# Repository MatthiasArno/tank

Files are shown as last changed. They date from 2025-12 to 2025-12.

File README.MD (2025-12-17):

# Ultrasonic Level Meter with Temperature Sensors, Dashboard and Chatbot Integration

<table>
  <tr>    
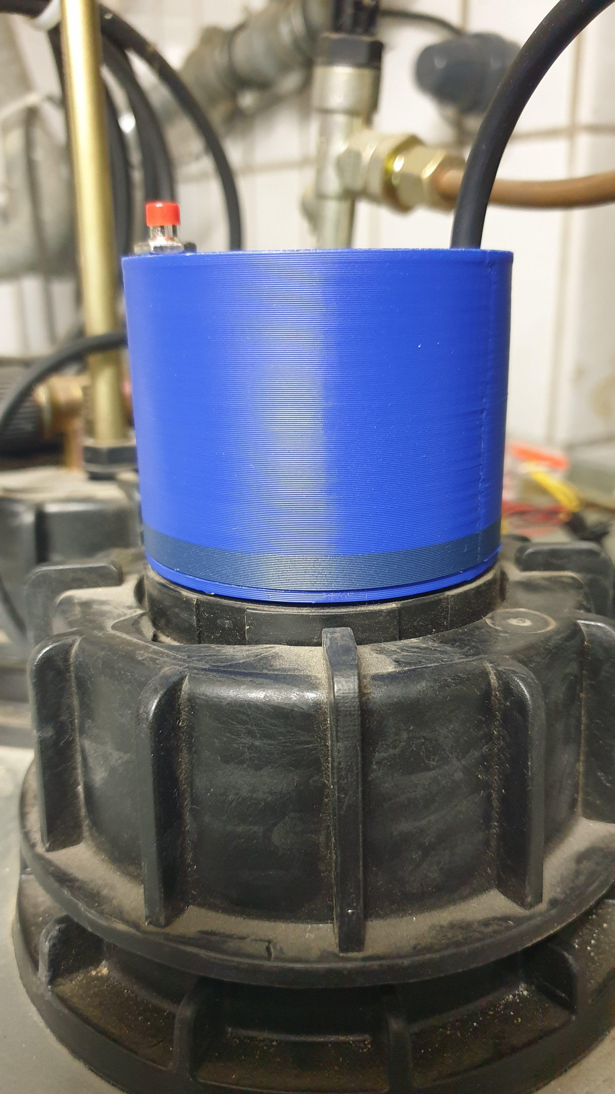
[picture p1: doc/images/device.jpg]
    <td width="50%"></td>
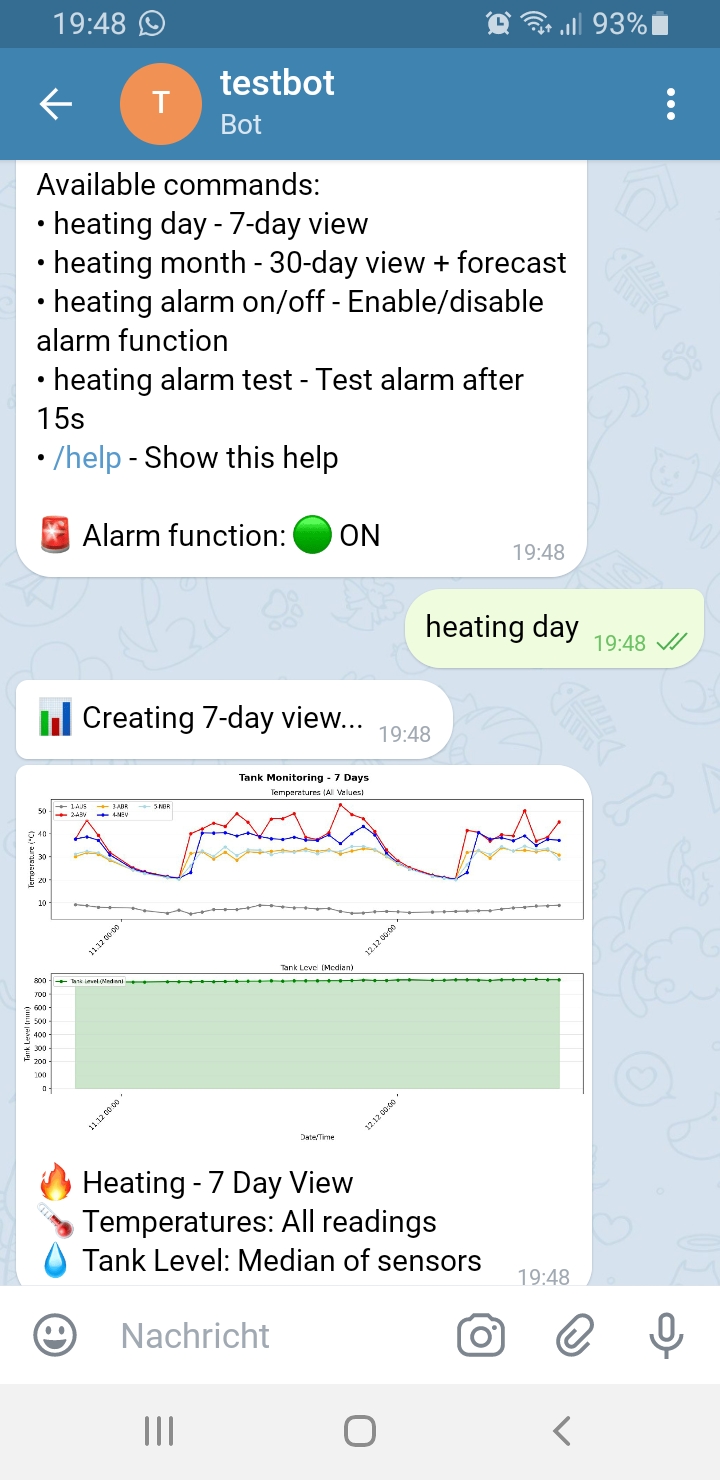
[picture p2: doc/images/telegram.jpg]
    <td width="50%"></td>
  </tr>
</table>
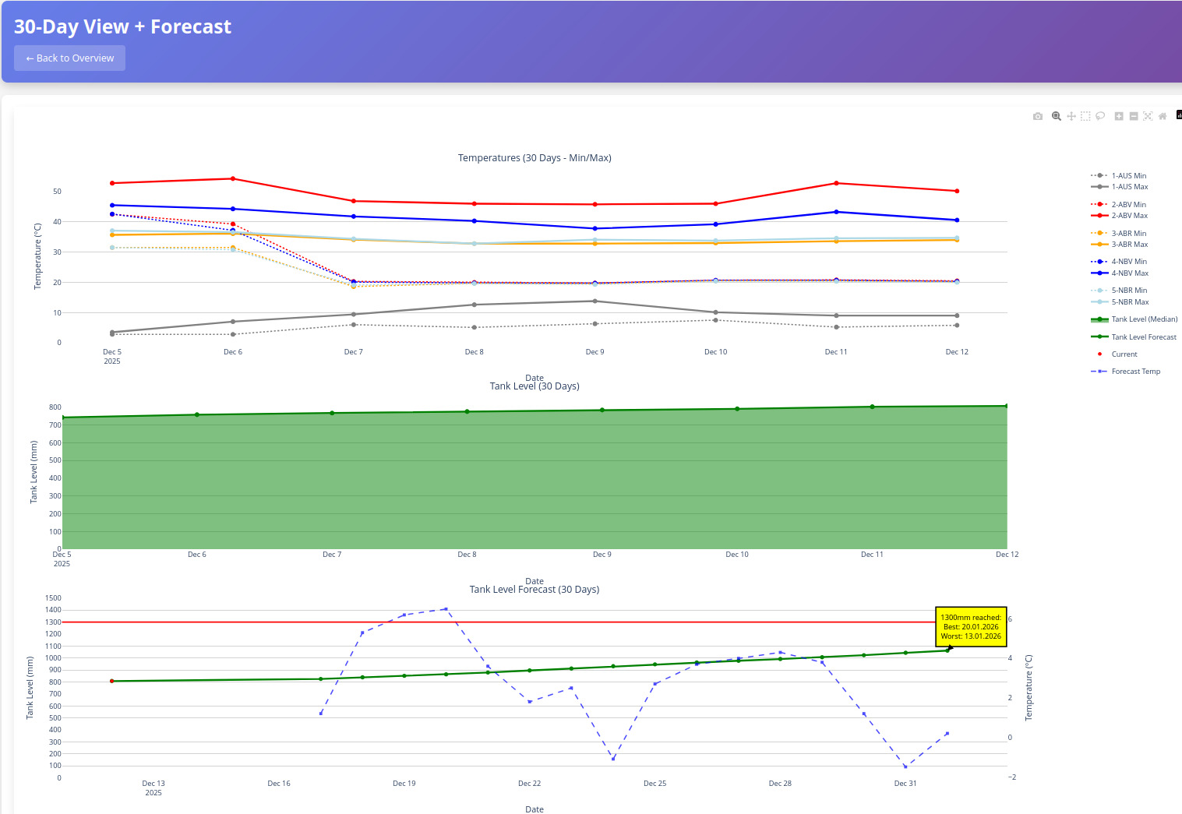
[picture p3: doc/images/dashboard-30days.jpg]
</td>
 
# Overwiew

This tank level monitor measures the current fill level and temperatures using ultrasonic SR04 and DS18B20 sensors.
With this data, I want to learn more about the future sizing of a heat pump—see also my initial thoughts on this [here](https://github.com/MatthiasArno/heizungsgesetz). The features in detail:

* Mechanical
  * 3dp parts available
  * 3xAA battery powered
* ESP32-based ultrasonic level meter with support for 5 external temperature sensors
  * Web interface for sensor readings, log download and software update
  * MQTT publishing of sensor data
* Raspberry Pi server
  * Statistics dashboard
  * Telegram bot (for remote access and alarms)
  * Alerting when temperatures fall below critical values
  * Tank level forecasting using historical data and weather forecasts

## Security & Disclaimer

**IMPORTANT:** This is a hobby project for personal, non-commercial use in controlled environments. It is provided "as-is" without warranty. By using this project, you accept all risks and responsibilities.

**Known Security Limitations:**

* WiFi credentials stored in plaintext on ESP32/.env
* Web interface is http and has no authentication
* MQTT communication unencrypted by default
* No secure boot implementation

**Required Security Measures:**

* **MANDATORY:** Isolate device on guest network with no internet access
* **MANDATORY:** Secure physical access to prevent credential theft
* **MANDATORY:** Set your Telegram user-id to prevent unauthorized bot access
* **MANDATORY:** Never port-forward the web interface to the internet (applies to device and dashboard server)
* Use dedicated MQTT server (e.g., Raspberry Pi)
* Run services as non-root user (default: **tank**)

**Recommended Hardening (currently not implemented):**

* Enable ESP32 secure boot
* Implement MQTT client authorization
* Add web interface authentication

**You are solely responsible for:**
* Network security and isolation
* Physical device security
* Any consequences of unauthorized access
* Compliance with local regulations

**This device is NOT suitable for critical infrastructure or commercial deployments.**

## Safety

**WARNING:** This device operates near flammable liquids. Improper use may result in fire, injury, or property damage.

**FIRE HAZARD - Critical Requirements:**

* **ONLY use standard alkaline AA batteries** - Never use rechargeable batteries
* Rechargeable batteries can supply high currents causing excessive heat and fire risk
* Installation on oil tanks or near flammable materials requires extreme caution
* Regularly inspect for signs of battery leakage, corrosion, or overheating

**Battery Specifications:**

* Type: Standard alkaline AA batteries only
* Expected lifetime: ~1 year under normal conditions (varies with environmental conditions, see below)
* Replace immediately if device behavior becomes erratic

**Installation Safety:**

* Mount securely to prevent falls into tank or flammable materials
* Ensure all connections are properly insulated and separated

**User Responsibility:**

You assume all liability for safe installation, operation, and maintenance. The author accepts no responsibility for fire, equipment damage, or personal injury resulting from use of this device.

**If unsure about safe installation, consult a qualified professional.**

## Operation

* Sensors
  * 1-AUS : Outside Temperature (Außentemperatur)
  * 2-ABV: Old Building Flow (Altbau Vorlauf)
  * 3-ABR: Old Building Return (Altbau Rücklauf)
  * 4-NBV: New Building Flow (Neubau Vorlauf)
  * 5-NBR: New Building Return (Neubau Rücklauf)
  * device: ESP32, +20 above room temp right after power up (when sending mqtt messages)
* The device sends an MQTT message each full hour with topics
  * tank/1/level, with level=a,b,c,1, beeing 3 consecutive level measurements in mm plus 1 (a constant, see code)
  * tank/sensorID/temp, with sensorID=device or serial ID of the temperature sensor or its name-mapping
* Dynamic sleep time and report
  * Dynamic sleep less than one hour under following conditions
    * 15 mins if 1-AUS falls below 3 degrees Celsius
    * 5 mins if 1-AUS below -8 degrees Celsius
  * Report sent (alarm)
    * If any heating temperature falls below 17 degree
    * If 1-AUS is below 4 degree Celsius and any heating temperature falls below 25 degree
* Pushing the KEY button for 2..3s will restart in WebMode
  * Terminate by the WebIF Exit Button
  * Terminate by pushing the button for longer than 10s
  * Terminate by closing the browser window (60 seconds without request, e.g. time update in the WebIF)  
* Blue LED
  * Lights directly after restart until deep_sleep
  * Flashes 100ms with 1s period in WebMode
* Power LED
  * Is desoldered to save energy

## Programming

https://micropython.org/download/ESP32_GENERIC/

```bash
# Setup micropython V1.26.1 (recent as of this days)
esptool erase_flash
esptool --baud 460800 write_flash 0x1000 ESP32_BOARD_NAME-DATE-VERSION.bin
# Compile the biggest files
mpy-cross main_tank.py microdot.py
# Keep KEY button pressed on device if there is already a SW installed, then copy the files
# Never write programms that immediately shutdown/sleep the device: this needs a reflashing of the micropython image
mpremote cp main_tank.mpy microdot.mpy pf_esp32.py main.py env.py :/
# Keep button pressed, then CTRL-C/CTRL-D to restart in WEB Mode
```

# Micropython

It is required to compile main_tank.py, microdot.py, otherwise out of memory or strange behavior will be the result. 

Cross compile: https://docs.micropython.org/en/v1.14/develop/gettingstarted.html
mpy-cross ...

## Dependencies

* mpremote mip install umqtt.simple

## ESP32 D1 WROOM Resources
[ESP32 D1 Pinout](https://www.az-delivery.de/en/blogs/azdelivery-blog-fur-arduino-und-raspberry-pi/das-dreiundzwanzigste-turchen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)

## Modifications

* Remove Power Led (red) to save energy

## Pin Usage

USB points to south, only pins on the east upper and lower side are used. Color of the cable depends what you have available.

Outer row, from north, 4x:
- GND (black)
- GPIO27: SR04_ECHO_PIN (green)
- GPIO25: SR04_TRIGGER_PIN (yellow)
- GPIO32: SR04_PWR_OUT (POWER) (red)

Inner row, from south, 6x:
- GPIO17: Sensor_PLUS (white)
- GPIO16: Sensor_BUS (grey)
- GND: Batt_GND, Sensor_GND, KEY_GND
- 5V: Batt_PLUS
- GPIO15: KEY_IN (internal Pullup, RTC capable wakeup)
- nc

Sensor Cable:
- Brown : GND
- Grey: Signal Temp
- Yello : +3.3V Temp
- White : nc
- Green :nc

## Sensor Codings

Up to 5 external temperature sensors will be supported. 1wire sensors have a unique device id, which will be reported along with its temperature value. For better reading, the last 2 hex digits of this id are mapped onto a clear name, e.g. 1-AUS. See code for the mapping.

Example: 28d35452000000d6 : -> translates to { "d6": "1-AUS"... }

## WiFi Connection

Unstable WiFi results in strange behavior of the device. When using a repeater, do not operate it in mesh mode since esp32 always tries to connect to the mesh master, regardless of the signal strength of your repeater. Instead, give the repeater a dedicated SSID and connect to it.

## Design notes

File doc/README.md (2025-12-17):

# Tank Monitoring System

Server applications for visualization, messaging and analysis of heating data.

## Structure

```
rpi/
├── db/                     # Database directory
│   └── tank_data.db       # SQLite database (created automatically)
└── src/                    # Source Code
    ├── api/                    # FastAPI Dashboard
    │   ├── dashboard.py       # Main application with Plotly
    │   └── templates/         # HTML Templates
    │       ├── index.html     # Home page
    │       └── view.html      # Chart view
    ├── database/              # Database modules
    │   └── db_handler.py     # Database handler
    ├── mqtt/                  # MQTT Client
    │   └── subscriber.py     # MQTT Subscriber
    ├── utils/                 # Utility functions
    ├── config.py             # Configuration
    ├── run_subscriber.py     # Starts MQTT Subscriber
    ├── run_dashboard.py      # Starts Dashboard
    ├── export_db.py          # DB Export Tool (R-FUN-700)
    ├── statistic_db.py       # Statistics Analysis Tool (F-STAT-800)
    ├── debug_db.py           # Database debug tool
    └── requirements.txt      # Python Dependencies
```

## Installation

### 1. Create Virtual Environment (recommended)

```bash
cd rpi/src
python3 -m venv .venv
source .venv/bin/activate
```

### 2. Install Python Dependencies

```bash
# In the activated venv:
pip install -r requirements.txt
```

**Important**: If you use a venv, you must activate it before each manual start:
```bash
source .venv/bin/activate
```

For systemd services, the absolute path to venv Python is used (see below).

### 3. Create Configuration

```bash
# Copy env.example to .env
cp env.example .env

# Edit .env and add your values
nano .env
```
### 4. Install Mosquitto MQTT Broker (if not already installed)

```bash
sudo apt update
sudo apt install mosquitto mosquitto-clients
sudo systemctl enable mosquitto
sudo systemctl start mosquitto
```
# Database (optional, default: ../db/tank_data.db)
# DATABASE_PATH=/custom/path/to/tank_data.db

### Start MQTT Subscriber

The subscriber receives MQTT messages and writes them to the database:

```bash
python3 run_subscriber.py
```

### Start Dashboard

The dashboard displays the data graphically:

```bash
python3 run_dashboard.py
```

Open dashboard: http://localhost:8000

### Start Messenger

```bash
python3 run_telegram_bot.py
```

Using a loud alarm tone:
* Download a loud sound, e.g. copy alarm.mp3 to /Notifications/alarm.mp3
* Telegram: Settings/Notifications
  * Private Chats: Sound+Vibration. A default must be enabled
  * Settings for system notifications (at the bottom): All customized channels at a glance
  * Customize channel directly: click on the icon in the channel, Notifications/Customize, then select your own alarm tone
* Phone:
  * Settings/Device maintenance/Battery/App power management/Apps that won't be put to sleep => Add Telegram
  * Settings/Apps/Telegram/Mobile data connection => Allow background data

### DB Export Tool

Exports database contents with optional date filters:

```bash
# Export all data
python3 export_db.py

# From start date
python3 export_db.py 2025-12-01

# Date range
python3 export_db.py 2025-12-01 2025-12-31
```

### Statistics Tool

Analyzes heating oil consumption depending on outside temperature:

```bash
# Analyze all data
python3 statistic_db.py

# From start date
python3 statistic_db.py 2025-12-01

# Date range
python3 statistic_db.py 2025-12-01 2025-12-31
```

The tool:
- Calculates daily consumption (dH/dT) normalized to outside temperature
- Performs linear regression and evaluates suitability
- Creates graphs PNG with actual data and regression line
- Saves graphs in the `output/` directory

### Debug Tool

Shows database statistics and diagnoses problems:

```bash
python3 debug_db.py
```

## Features

### MQTT Topics

The subscriber subscribes to the following topics:
- `tank/1/level` - Level measurements (3 values + ignored value)
- `tank/1/temp/1-AUS` - Outside temperature
- `tank/1/temp/2-ABV` - Old building supply (R-FUN-110)
- `tank/1/temp/3-ABR` - Old building return (R-FUN-110)
- `tank/1/temp/4-NBV` - New building supply (R-FUN-110)
- `tank/1/temp/5-NBR` - New building return (R-FUN-110)
- `tank/1/temp/device` - Ignored

### Dashboard

FastAPI-based dashboard with two main views:

### R-FUN-510/520/530: 30-Day View

- Shows min/max values of all temperature sensors over 30 days
- Dotted lines for min values, solid lines for max values
- Color coding (R-FUN-530):
  - ABV (Old building supply): Red
  - ABR (Old building return): Orange
  - NBV (New building supply): Blue
  - NBR (New building return): Light blue
  - Level: Green
- Level: Last value of the day (median of 3 sensors)

### 7-Day View

- Shows all values (hourly aggregated) over 7 days
- Solid lines for all sensors
- Level: Median of 3 sensors
- Same color coding as 30-day view

### DB Export Tool

Command-line tool for exporting database data:

```bash
python3 export_db.py [STARTDATE] [ENDDATE]
```

- No parameters: All data
- One parameter: From start date
- Two parameters: Date range
- Date format: YYYY-MM-DD

### Statistical Analysis

Analyzes the relationship between heating oil consumption and outside temperature:

```bash
python3 statistic_db.py [STARTDATE] [ENDDATE]
```

Functions:
- Calculates daily consumption rate normalized to temperature difference to 20°C: `dH/dT = (H_end - H_start) / (T_mean - 20)` [mm/Kelvin]
- Optional date filters (analogous to export_db.py)
- Linear regression with statistical evaluation (R², p-value)
- Graphical representation:
  - X-axis: Outside temperature [°C]
  - Y-axis: Daily consumption [mm]
  - Shows measurement data as points and regression line
  - Saves as PNG and PDF in `output/` directory

## Important Note: Dashboard Display

The dashboard shows data from the last 7/30 days by default. If no data is available in this time period (e.g., with older test data), the logic has been improved:

- **Automatic fallback display**: If no current data is available, the last available data is automatically displayed
- **Debug tool**: With `python3 debug_db.py` you can check what data is in the DB and how old it is

## Database

The SQLite database is stored by default in `rpi/db/tank_data.db` and contains two tables:

- `level_measurements`: Level measurements
- `temp_measurements`: Temperature measurements

Both tables contain timestamp, tank ID, and the respective measurement values.

**Database location**:
- Default: `rpi/db/tank_data.db`
- Automatically created on first start
- Can be changed via `DATABASE_PATH` environment variable

## Debian Package Installation

A Debian package is available for easy installation on the Raspberry Pi. See the *build-deb-fpm.sh* for systemd configuration and what gets packed.

### Create Package (on development computer)

Prerequisites:
```bash
sudo apt-get install -y ruby ruby-dev rubygems build-essential
sudo gem install --no-document fpm
```

Build package:
```bash
cd /path/to/project
./build-deb-fpm.sh
```

Creates: `tank-monitoring_0.1.0_armhf.deb`

### Install Package on RPI

```bash

# Install Mosquitto
sudo apt-get install mosquitto
# Create file
# etc/mosquitto/conf.d/rpiserver.conf
# listener 1883 0.0.0.0
# allow_anonymous true
sudo systemctl enable mosquitto
sudo systemctl start mosquitto

# Copy package to RPI
scp tank-monitoring_0.1.0_armhf.deb myuser@myrpi:~

# Install on RPI
ssh myuser@myrpi
sudo dpkg -i tank-monitoring_0.1.0_armhf.deb
sudo apt-get install -f  # If dependencies are missing
```

### Configuration After Installation

```bash
# 1. Create bot configuration
sudo cp /etc/tank/bot.conf.example /etc/tank/bot.conf
sudo nano /etc/tank/bot.conf
```

Add:
```bash
TELEGRAM_BOT_TOKEN=your-bot-token-here
TELEGRAM_MY_ID=your-telegram-user-id
```

```bash
# 2. Enable and start services
sudo systemctl enable tank-subscriber tank-telegram
sudo systemctl start tank-subscriber tank-telegram

# Optional: Enable dashboard
sudo systemctl enable tank-dashboard
sudo systemctl start tank-dashboard
```

### Service Management with tank-ctl

The package installs a helper script for easy service management:

```bash
# Start services
tank-ctl start

# Stop services
tank-ctl stop

# Restart services
tank-ctl restart

# Show status of all services
tank-ctl status

# View logs
tank-ctl logs mqtt        # MQTT Subscriber logs
tank-ctl logs bot         # Telegram Bot logs
tank-ctl logs dashboard   # Dashboard logs

# Enable/disable autostart
tank-ctl enable
tank-ctl disable
```

### Control Individual Services

```bash
# MQTT Subscriber only
sudo systemctl start tank-subscriber
sudo systemctl stop tank-subscriber
sudo systemctl status tank-subscriber

# Telegram Bot only
sudo systemctl start tank-telegram
sudo systemctl stop tank-telegram
sudo systemctl status tank-telegram

# Dashboard only
sudo systemctl start tank-dashboard
sudo systemctl stop tank-dashboard
sudo systemctl status tank-dashboard
```

### Installation Paths

The Debian package installs to:
- Application: `/opt/tank/rpi/`
- Python venv: `/opt/tank/rpi/.venv/`
- Database: `/opt/tank/rpi/db/tank_data.db`
- Configuration: `.env' : provide your personal configuration file
- Systemd services: `/etc/systemd/system/tank-*.service`
- Helper script: `/usr/bin/tank-ctl`

### Uninstallation

```bash
# Services are automatically stopped and disabled
sudo dpkg -r tank-monitoring

# Complete removal including database and configuration
sudo dpkg --purge tank-monitoring
sudo rm -rf /opt/tank
```

### Logs After Installation

```bash
# Real-time logs
sudo journalctl -u tank-subscriber -f
sudo journalctl -u tank-telegram -f
sudo journalctl -u tank-dashboard -f

# Or with tank-ctl
tank-ctl logs mqtt
tank-ctl logs bot
tank-ctl logs dashboard
```

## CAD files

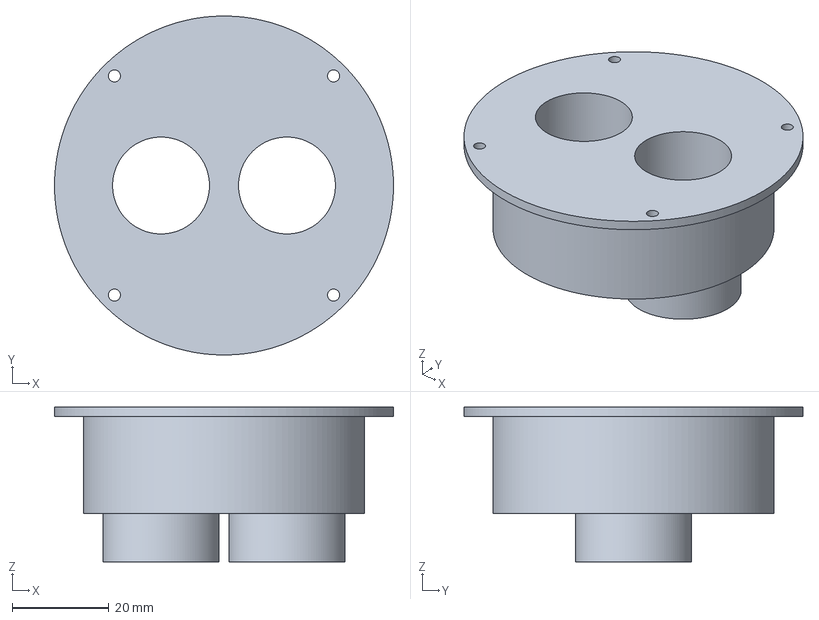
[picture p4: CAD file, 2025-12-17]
mech/bambu/tank-BBoden.amf
70.0 x 70.0 x 32.0 mm

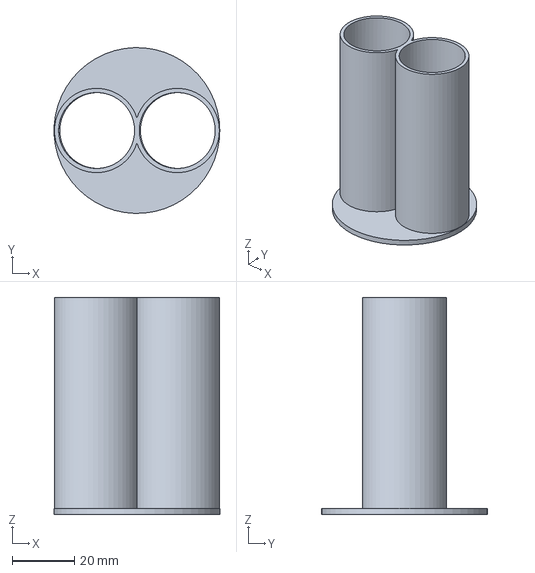
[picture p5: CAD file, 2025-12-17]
mech/tank.FCStd
53.4 x 53.5 x 70.0 mm

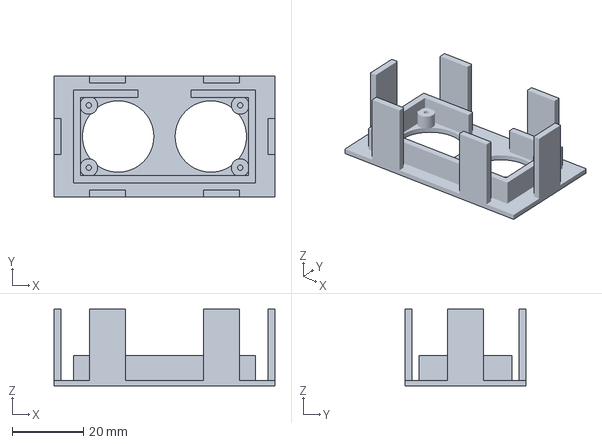
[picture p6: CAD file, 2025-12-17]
mech/bambu/tank-BHalter.amf
62.0 x 34.0 x 21.5 mm

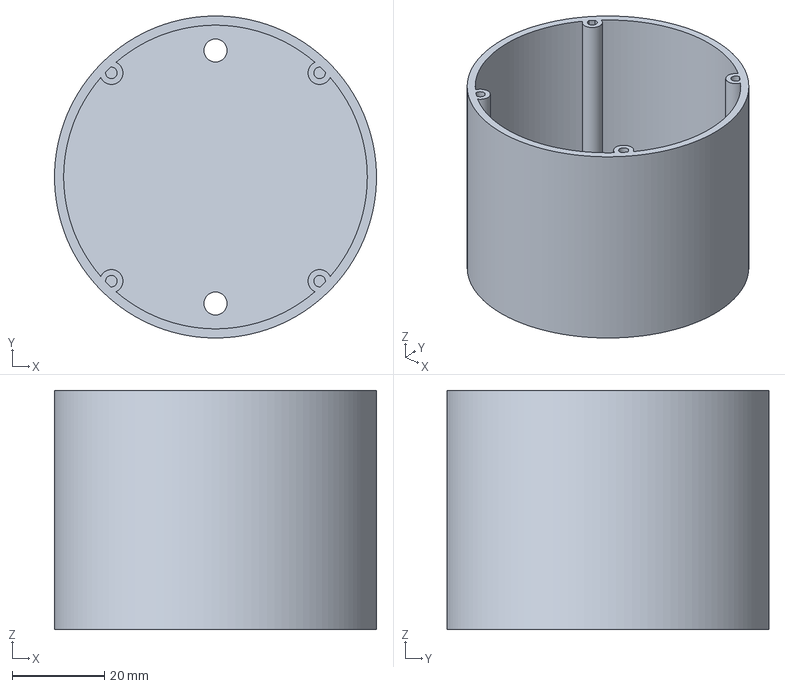
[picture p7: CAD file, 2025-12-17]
mech/bambu/tank-BDeckel.amf
70.0 x 70.0 x 52.0 mm

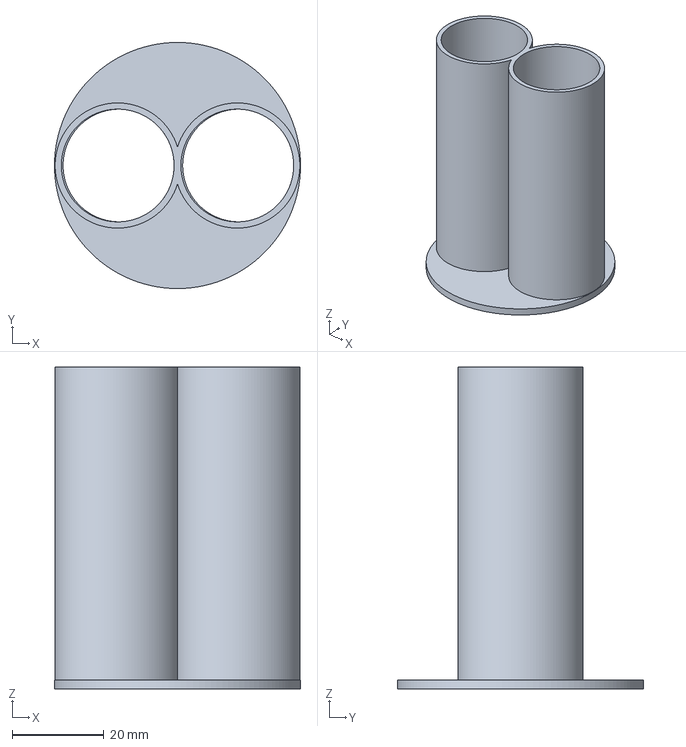
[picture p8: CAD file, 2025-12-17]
mech/bambu/tank-BSoundPipe.amf
53.5 x 53.5 x 70.0 mm

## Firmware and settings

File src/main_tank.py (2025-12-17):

"""
Tank Level Measurement System
Measures oil tank level via HC-SR04 ultrasonic sensor
Supports ESP32 and Raspberry Pi Pico
"""

import time
import network
import ntptime
import machine
import gc
import os
import sys
from machine import Pin, WDT

# Use ujson for MicroPython (more efficient than standard json)
try:
    import ujson as json
except ImportError:
    import json

try:
    import uasyncio as asyncio
except ImportError:
    import asyncio

try:
    import umqtt.simple as mqtt
except ImportError:
    mqtt = None

try:
    from microdot import Microdot, Response, Request
except ImportError:
    print("ERROR: Microdot not found!")
    raise

from env import *

try:
    from ds18x20 import DS18X20
    from onewire import OneWire
except ImportError:
    DS18X20 = None
    OneWire = None


try:
    from esp32 import wake_on_ext0
except ImportError:
    wake_on_ext0 = None

# Detect platform
try:
    from pf_esp32 import *
    PLATFORM = "ESP32"
except ImportError:
    try:
        from pf_rpi import *
        PLATFORM = "RPI_PICO"        
    except ImportError:
        print("ERROR: No platform file!")
        raise


#MQTT_SERVER = "your-server" (use env.py instead!)
ntptime.host = "192.53.103.104"
Request.max_content_length = 256 * 1024
Request.max_body_length = 2 * 1024

# Global state for restart
launch_restart_pending = False


# Temperature sensors, sorted by name when returned
temp_id_to_name={ "device": "device", "d6" : "1-AUS", "5a" : "2-ABV", "2b" : "3-ABR", "89" : "4-NBV", "49": "5-NBR"}


# Wakeup each minutes, relative to the last full hour
TIMEOUT_REPORT_WAKEUP=60*60
# T_aus determines the wakeup time
T_aus=0
# Temperatures for different wakeup times in 1/10 Celsius
TEMP_15MIN_WAKEUP=30
TIMEOUT_15MIN_WAKEUP=15*60

TEMP_5MIN_WAKEUP=-80
TIMEOUT_5MIN_WAKEUP=5*60

ALARM_TEMP_THRESHOLD_HIGH=250
ALARM_TEMP_THRESHOLD_AUS=40       
ALARM_TEMP_THRESHOLD_LOW=170        

LOGFILE="/log.csv"
# Import stubs here to allow overriding of constants
#from stubs import *

def median(values):
    """Return median of values"""
    if not values:
        return 0
    sorted_vals = sorted(values)
    return sorted_vals[len(sorted_vals) // 2]


def get_memory_usage():
    """Get memory usage statistics"""
    try:
        gc.collect()
        mem_free = gc.mem_free()
        mem_alloc = gc.mem_alloc()
        mem_total = mem_free + mem_alloc

        if mem_total > 0:
            percent_used = (mem_alloc * 100) // mem_total
        else:
            percent_used = 0

        used_kb = mem_alloc // 1024
        total_kb = mem_total // 1024
        return f"{used_kb}KB / {total_kb}KB ({percent_used}%)"
    except Exception as e:
        return f"Error: {e}"


# async def measure_vbus_voltage():
#     """Measure VBUS voltage on ESP32 (async)

#     Uses ADC2 channel 8 (GPIO4) which is connected to VBUS
#     Returns voltage in mV (0-5500 mV typical for USB)
#     Returns -1 if measurement fails
#     """
#     try:
#         from machine import ADC

#         # ESP32 VBUS is typically on ADC2_CH8 (GPIO4)
#         # Voltage divider: VBUS/2 to allow 5V input on 3.3V ADC
#         # Formula: VBUS_mV = (ADC_reading / 4095) * 3300 * 2
#         adc = ADC(machine.Pin(4))
#         adc.atten(ADC.ATTN_11DB)  # 0-3.6V range
#         adc.width(ADC.WIDTH_12BIT)  # 12-bit resolution (0-4095)

#         # Take multiple readings for stability
#         readings = []
#         for _ in range(5):
#             reading = adc.read()
#             # Convert ADC reading to VBUS voltage in mV
#             # With voltage divider (VBUS/2): actual_voltage = (adc_reading / 4095) * 3300 * 2
#             vbus_mv = (reading * 3300 * 2) // 4095
#             readings.append(vbus_mv)
#             await asyncio.sleep_ms(10)

#         # Return median to filter noise
#         vbus_mv = median(readings)
#         print(f"  VBUS: {vbus_mv} mV ({vbus_mv/1000:.2f}V)")
#         return vbus_mv

#     except Exception as e:
#         print(f"  VBUS measurement error: {e}")
        return -1


def measure_distance_mm():
    """Measure distance using HC-SR04"""
    trigger = Pin(SR04_TRIGGER_PIN, Pin.OUT)
    echo = Pin(SR04_ECHO_PIN, Pin.IN)

    trigger.off()
    time.sleep_us(2)
    trigger.on()
    time.sleep_us(10)
    trigger.off()
    
    timeout = 30000
    start = time.ticks_us()
    pulse_start=start
    pulse_end=start
    
    while echo.value() == 0:
        if time.ticks_diff(time.ticks_us(), start) > timeout:
            return -1
        pulse_start = time.ticks_us()
    
    while echo.value() == 1:
        if time.ticks_diff(time.ticks_us(), start) > timeout:
            return -1
        pulse_end = time.ticks_us()
    
    pulse_duration = time.ticks_diff(pulse_end, pulse_start)
    distance = int((pulse_duration * 0.343) / 2)
    
    return distance


def activate_sr04_module(activate=True):    
    power_pin = Pin(SR04_PWR_OUT, Pin.OUT)
    if activate:
        power_pin.on()
    else:
        power_pin.off()


def activate_temp_module(activate=True):    
    power_pin = Pin(DS18B20_PWR, Pin.OUT)
    if activate:
        power_pin.on()
    else:
        power_pin.off()


async def measure_temperatures():
    """Measure temperature from ESP32 internal sensor + up to 5 DS18B20 sensors

    Returns:
        list: List of tuples (sensor_id, temp_int) where sensor_id is identifier
              and temp_int is temperature in °C * 10
    """
    readings = []

    # ESP32 internal temperature sensor (first)
    if PLATFORM == "ESP32":
        try:
            import esp32
            # esp32.raw_temperature() returns raw ADC value, convert to Celsius
            # Formula: T = (raw_value - 32) / 165 * 100 - 40 (approximately)
            raw_temp = esp32.raw_temperature()
            # Simpler conversion that works for ESP32
            temp_c = (raw_temp - 32) / 1.8
            temp_int = int(temp_c * 10)
            readings.append(("device", temp_int))
            print(f"  ESP32 device: {temp_c:.1f}°C ({temp_int}) [raw={raw_temp}]")
        except Exception as e:
            print(f"  ESP32 device sensor: Error - {e}")

    # DS18B20 sensors on 1-Wire bus (up to 4 remaining)
    if DS18X20 is None or OneWire is None:
        if not readings:
            print("WARNING: DS18X20/OneWire modules not available")
        return readings
        
    try:
        # Create 1-Wire bus on single pin
        ow = OneWire(Pin(DS18B20_BUS))
        ds = DS18X20(ow)

        # Scan for connected devices
        devices = ow.scan()
        if not devices:        
            print("No DS18B20 sensors found")
            return readings

        # Convert to list and limit to 5 sensors (1st is ESP32 internal)
        sensor_ids = list(devices)[:5]
        print(f"Found {len(sensor_ids)} DS18B20 sensor(s)")

        # Trigger temperature conversion on all devices
        ds.convert_temp()

        # Read temperatures              
        for i, rom in enumerate(sensor_ids):
            try:
                temp_c = ds.read_temp(rom)
                # Convert to integer (°C * 10) to preserve one decimal place
                temp_int = int(temp_c * 10)
                # Convert ROM (bytes) to hex string (48-bit address)
                rom_hex = rom.hex() if hasattr(rom, 'hex') else ''.join(f'{b:02x}' for b in rom)
                rom_crc=rom_hex[-2:]
                if rom_crc in temp_id_to_name:
                    rom_hex=temp_id_to_name[rom_crc]
                readings.append((rom_hex, temp_int))
                print(f"  DS18B20 {i+1} ({rom_hex}): {temp_c:.1f}°C ({temp_int})")
            except Exception as e:
                print(f"  DS18B20 {i+1}: Error - {e}")
            await asyncio.sleep_ms(0)

        return sorted(readings)
    except Exception as e:
        print(f"✗ Temperature measurement error: {e}")
        return readings    


def convert_dist(dist_mm):
    """Convert distances to normalized values (user fills this), last element is liter.
       Currently, filling levels, i.e. air gap, in mm from top to oil level are reported. Liter is set to 1 wthout any meaning.
    """
    return dist_mm+[1]

class TankMonitor:    

    def __init__(self):
        """Initialize the tank monitoring system"""
        self.wdt = WDT(timeout=15000)
        self.wlan = network.WLAN(network.STA_IF)
        self.app = Microdot()
        self.mqtt_client = None
        self.web_mode_active = False
        self.web_server_running = False
        self.current_datetime_str = "01.01.2000 00:00:00"
        self.last_measurement_time = "01.01.2000 00:00:00"
        self.distance_measurements = [0,0,0]
        self.temperature_readings = []
        #self.vbus_voltage = 0
        self.key_press_time = 0
        self.key_pressed = False
        self.key_released = False
        self.key_pressed_at_startup = False
        self.last_web_request_time = 0
    
        
        """Monitor KEY button"""
        self.key_pin = Pin(KEY_GPIO_IN, Pin.IN, Pin.PULL_UP)
        self.key_pin.irq(trigger=Pin.IRQ_FALLING)

        # Onboard LED for web mode indication (GPIO2 on ESP32)
        self.status_led = Pin(2, Pin.OUT)
        self.status_led.off()

        # Enable watchdog timer        
        #print("✓ Watchdog enabled (15s timeout)")

        # ESP32: Configure external wakeup from deep sleep (active LOW)
        if PLATFORM == "ESP32" and wake_on_ext0 is not None:
            try:
                wake_on_ext0(pin=KEY_GPIO_IN, level=False)
                print(f"✓ ESP32 external wakeup enabled on GPIO{KEY_GPIO_IN}")
            except Exception as e:
                print(f"✗ ESP32 external wakeup setup failed: {e}")

        # Setup routes
        self._setup_routes()

    def _setup_routes(self):
        """Setup all web routes"""

        @self.app.before_request
        async def before_request_handler(request):
            """Update last request time before each request"""
            self.last_web_request_time = time.time()

        @self.app.route("/")
        async def index(request):
            """Main web page"""
            html = """
        <!DOCTYPE html>
        <html>
        <head>
            <meta charset="UTF-8">
            <meta name="viewport" content="width=device-width, initial-scale=1">
            <title>Tank Monitor</title>
            <style>
                body {
                    font-family: Arial, sans-serif;
                    max-width: 800px;
                    margin: 20px auto;
                    padding: 20px;
                    background-color: #f0f0f0;
                }
                .container {
                    background-color: white;
                    border-radius: 10px;
                    padding: 30px;
                    box-shadow: 0 2px 10px rgba(0,0,0,0.1);
                }
                h1 {
                    color: #333;
                    border-bottom: 2px solid #4CAF50;
                    padding-bottom: 10px;
                }
                .info-box {
                    background-color: #f9f9f9;
                    border-left: 4px solid #4CAF50;
                    padding: 15px;
                    margin: 15px 0;
                }
                .info-box h3 {
                    margin-top: 0;
                    color: #4CAF50;
                }
                button {
                    background-color: #4CAF50;
                    color: white;
                    padding: 12px 24px;
                    border: none;
                    border-radius: 4px;
                    cursor: pointer;
                    font-size: 14px;
                    margin: 5px;
                }
                button:hover { background-color: #45a049; }
                button.danger { background-color: #d32f2f; }
                button.danger:hover { background-color: #c62828; }
                button.upload { background-color: #ff9800; }
                button.upload:hover { background-color: #e68900; }
                #upload-progress { display: none; margin-top: 10px; }
                .progress-bar {
                    width: 100%;
                    height: 20px;
                    background-color: #ddd;
                    border-radius: 4px;
                    overflow: hidden;
                }
                .progress-fill {
                    height: 100%;
                    background-color: #ff9800;
                    width: 0%;
                    transition: width 0.3s;
                }
            </style>
        </head>
        <body>
            <div class="container">
                <h1>⏱️ Tank Level Monitor V1.7.0</h1>

                <div class="info-box">
                    <h3>⏰ Current Time (Berlin)</h3>
                    <div id="datetime" style="font-size: 16px; font-weight: bold; color: #4CAF50;">Loading...</div>
                </div>

                <div class="info-box">
                    <h3>📊 Current Measurement</h3>
                    <div style="font-family: monospace; font-size: 14px;">
                        <div><span id="measure-time" style="color: #4CAF50; font-weight: bold;">--:--:--</span></div>
                        <div style="padding: 10px 0; border-top: 1px solid #ddd; border-bottom: 1px solid #ddd;">
                            <span id="val1">0</span> | <span id="val2">0</span> | <span id="val3">0</span> | <span id="val4" style="font-weight: bold; color: #4CAF50;">0</span>
                        </div>
                    </div>
                </div>

                <div class="info-box">
                    <h3>🌡️ Temperature Sensors</h3>
                    <div style="font-family: monospace; font-size: 13px;" id="temp-readings">
                        <div style="color: #999;">No sensors detected</div>
                    </div>
                </div>

                <!--
                <div class="info-box">
                    <h3>⚡ Power Supply</h3>
                    <div style="font-family: monospace; font-size: 14px;">
                        <div><b>VBUS:</b> <span id="vbus-voltage" style="color: #4CAF50; font-weight: bold;">--</span> V</div>
                    </div>
                </div>
                -->

                <div class="info-box">
                    <button onclick="publishCurrent()">📤 Publish</button>
                    <button onclick="downloadLog()">📥 Download Log</button>
                    <button class="danger" onclick="exitWebMode()">🔴 Exit Web Mode</button>
                </div>

                <div class="info-box">
                    <h3>📡 System Status</h3>
                    <div id="status">Loading...</div>
                    <hr style="margin: 10px 0; border: none; border-top: 1px solid #ddd;">
                    <div><b>Memory:</b> <span id="memory">--</span></div>
                </div>

                <div class="info-box">
                    <h3>🔧 Firmware Update</h3>
                    <input type="file" id="firmware-file" accept=".mpy">
                    <button class="upload" onclick="uploadFirmware()">📤 Upload Firmware</button>
                    <button class="upload" id="launch-button" onclick="launchFirmware()" style="display: none;">🚀 Launch Firmware</button>
                    <div id="upload-progress">
                        <div class="progress-bar">
                            <div id="upload-progress-fill" class="progress-fill"></div>
                        </div>
                        <div id="upload-status" style="margin-top: 5px;"></div>
                    </div>
                </div>
            </div>

            <script>
                async function updateStatus() {
                    try {
                        const response = await fetch('/api/status');
                        const data = await response.json();
                        document.getElementById('datetime').textContent = data.time;
                        document.getElementById('measure-time').textContent = data.measurement_time;
                        document.getElementById('val1').textContent = data.norm_dist[0];
                        document.getElementById('val2').textContent = data.norm_dist[1];
                        document.getElementById('val3').textContent = data.norm_dist[2];
                        document.getElementById('val4').textContent = data.norm_dist[3];
                        document.getElementById('status').innerHTML =
                            `<b>Mode:</b> WEB<br>` +
                            `<b>WiFi:</b> ${data.wifi_connected ? '✓ Connected' : '✗ Disconnected'}`;
                        document.getElementById('memory').textContent = data.memory;

                        /*
                        // Update VBUS voltage
                        if (data.vbus_voltage !== undefined && data.vbus_voltage >= 0) {
                            const vbusV = (data.vbus_voltage / 1000).toFixed(2);
                            document.getElementById('vbus-voltage').textContent = vbusV;
                        }
                        */

                        // Update temperature readings
                        const tempDiv = document.getElementById('temp-readings');
                        if (data.temperatures && data.temperatures.length > 0) {
                            let tempHtml = '';
                            for (let i = 0; i < data.temperatures.length; i++) {
                                const [serial, temp] = data.temperatures[i];
                                const tempC = (temp / 10).toFixed(1);
                                tempHtml += `<div>${serial}: <b>${tempC}°C</b></div>`;
                            }
                            tempDiv.innerHTML = tempHtml;
                        } else {
                            tempDiv.innerHTML = '<div style="color: #999;">No sensors detected</div>';
                        }
                    } catch (e) {
                        console.error('Status error: ' + e);
                    }
                }

                async function publishCurrent() {
                    try {
                        const response = await fetch('/api/publish');
                        const data = await response.json();
                        await updateStatus();
                    } catch (e) {
                        console.error('Publish error: ' + e);
                    }
                }

                async function downloadLog() {
                    window.location.href = '/api/log';
                }

                async function uploadFirmware() {
                    const file = document.getElementById('firmware-file').files[0];
                    if (!file) {
                        return;
                    }

                    const progressDiv = document.getElementById('upload-progress');
                    const progressFill = document.getElementById('upload-progress-fill');
                    const statusDiv = document.getElementById('upload-status');
                    const launchButton = document.getElementById('launch-button');

                    progressDiv.style.display = 'block';
                    progressFill.style.width = '0%';
                    statusDiv.textContent = 'Uploading...';
                    launchButton.style.display = 'none';

                    try {
                        const response = await fetch('/api/upload', {
                            method: 'POST',
                            body: file
                        });

                        const data = await response.json();
                        if (data.status === 'ok') {
                            progressFill.style.width = '100%';
                            statusDiv.textContent = '✓ Upload successful! ' + data.size + ' bytes';
                            statusDiv.style.color = '#4CAF50';
                            launchButton.style.display = 'inline-block';
                        } else {
                            statusDiv.textContent = '✗ Upload failed: ' + data.message;
                            statusDiv.style.color = '#d32f2f';
                        }
                    } catch (e) {
                        statusDiv.textContent = '✗ Error: ' + e;
                        statusDiv.style.color = '#d32f2f';
                    }
                }

                async function launchFirmware() {
                    try {
                        const response = await fetch('/api/launch', {
                            method: 'POST'
                        });

                        const data = await response.json();
                        if (data.status === 'ok') {
                            setTimeout(() => {
                                window.location.reload();
                            }, 2000);
                        }
                    } catch (e) {
                        // Server restarting is expected
                    }
                }

                async function exitWebMode() {
                    try {
                        const response = await fetch('/api/exit');
                        const data = await response.json();
                    } catch (e) {
                        // Server shutting down is expected
                    }
                }

                updateStatus();
                setInterval(updateStatus, 500);
            </script>
        </body>
        </html>
        """
            return Response(html, headers={"Content-Type": "text/html"})
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

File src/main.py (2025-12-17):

import machine, sys, time

try:
    import main_tank
    main_tank.start()    
except KeyboardInterrupt:
    print("Stopped by user")
    # Drop to REPL
except Exception as e:
    print("Fatal error - waiting 5s before reset")
    sys.print_exception(e)
    time.sleep(5)  # Time window to Ctrl-C
    machine.reset()
